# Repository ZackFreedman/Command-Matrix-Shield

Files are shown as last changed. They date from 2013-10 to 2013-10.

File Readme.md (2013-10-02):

The Command Matrix Shield is an expansion board for the ChipKit Uno32 that features an 8x8 LED matrix. The Command Matrix is bidirectional - you can display stuff on it, and sense light hitting it, simultaneously! It's the world's tiniest and most adorable touchscreen!

Important: This shield and the sketches are designed for ChipKIT, specifically the Uno32. THE CODE WILL NOT COMPILE UNDER ARDUINO - JUST MPIDE TARGETING THE UNO32. 

EAGLE files are stored in the folder "Command Matrix Shield PCB".

A straightforward debug program is in the folder "Command Matrix Shield Test". Expected behavior is to send coordinates over hardware serial at 9600 baud when a strong green or blue point light is shone at one of the pixels.

The software and hardware contain a large number of oversights, hacks, cut corners, and plain wrong decisions. Nevertheless, this is known working. Somehow.

Created by Zack Freedman of Voidstar Lab.
@ZackFreedman
yourstruly at zackfreedman com
zackfreedman.com
voidstarlab.com

For more information, visit http://zackfreedman.com/projects/command-matrix-shield/.

The Command Matrix Shield is open hardware licensed under Creative Commons Noncommercial Attribution. More permissive licenses are available on request.

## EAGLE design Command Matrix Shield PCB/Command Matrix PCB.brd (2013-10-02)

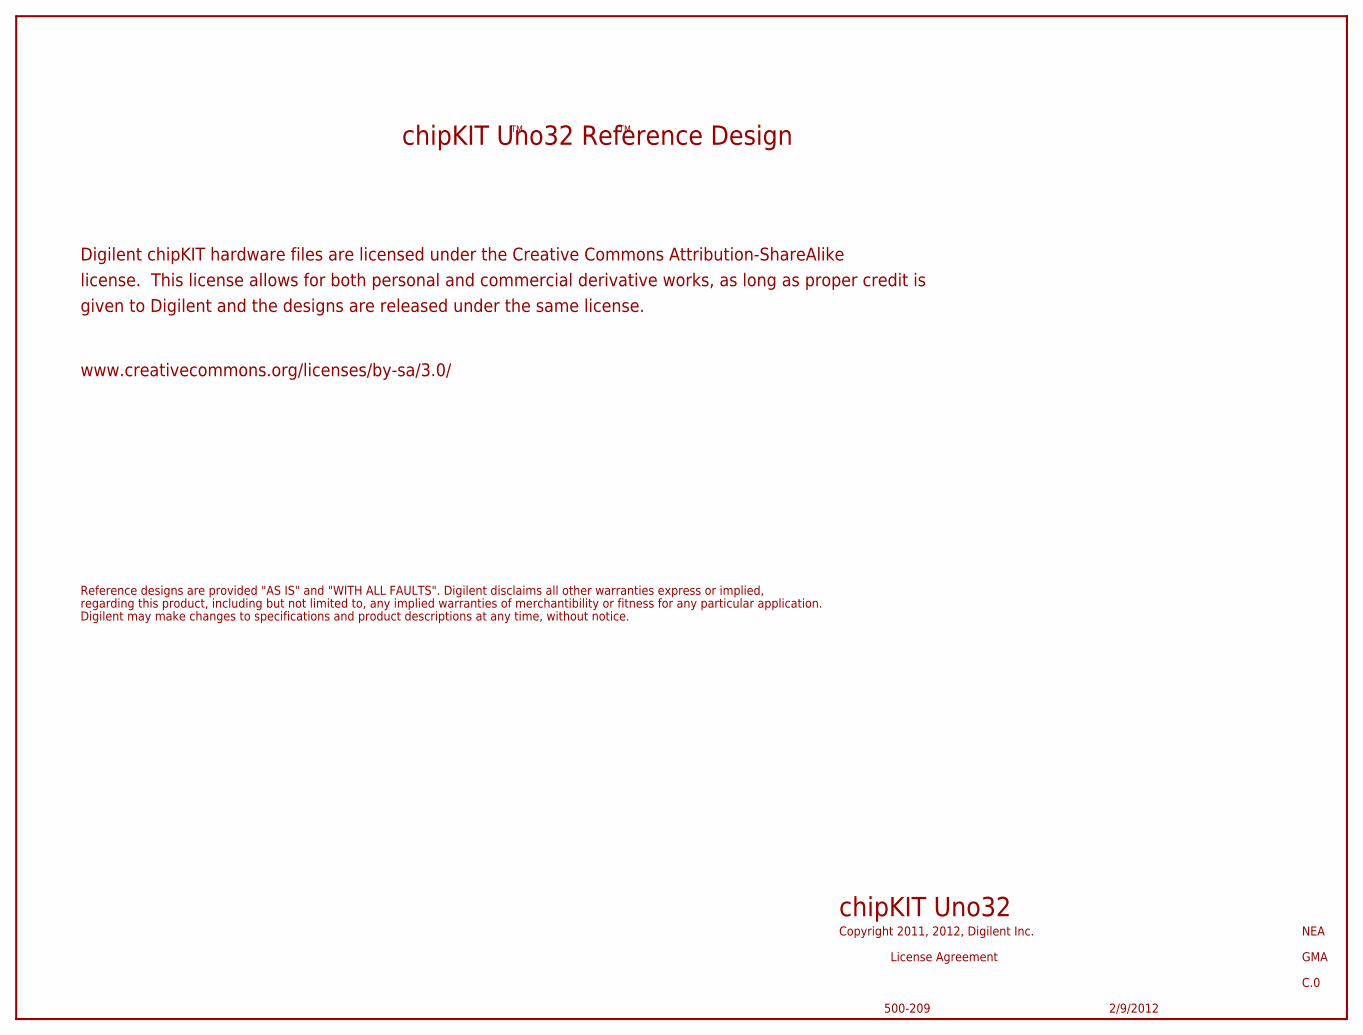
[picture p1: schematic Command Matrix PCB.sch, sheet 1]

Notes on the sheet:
Copyright 2011, 2012, Digilent Inc.
NEA
GMA
License Agreement
500-209
chipKIT Uno32
C.0
2/9/2012
Digilent chipKIT hardware files are licensed under the Creative Commons Attribution-ShareAlike
license. This license allows for both personal and commercial derivative works, as long as proper credit is
given to Digilent and the designs are released under the same license.
chipKIT Uno32 Reference Design
Reference designs are provided "AS IS" and "WITH ALL FAULTS". Digilent disclaims all other warranties express or implied,
regarding this product, including but not limited to, any implied warranties of merchantibility or fitness for any particular application.
Digilent may make changes to specifications and product descriptions at any time, without notice.
www.creativecommons.org/licenses/by-sa/3.0/

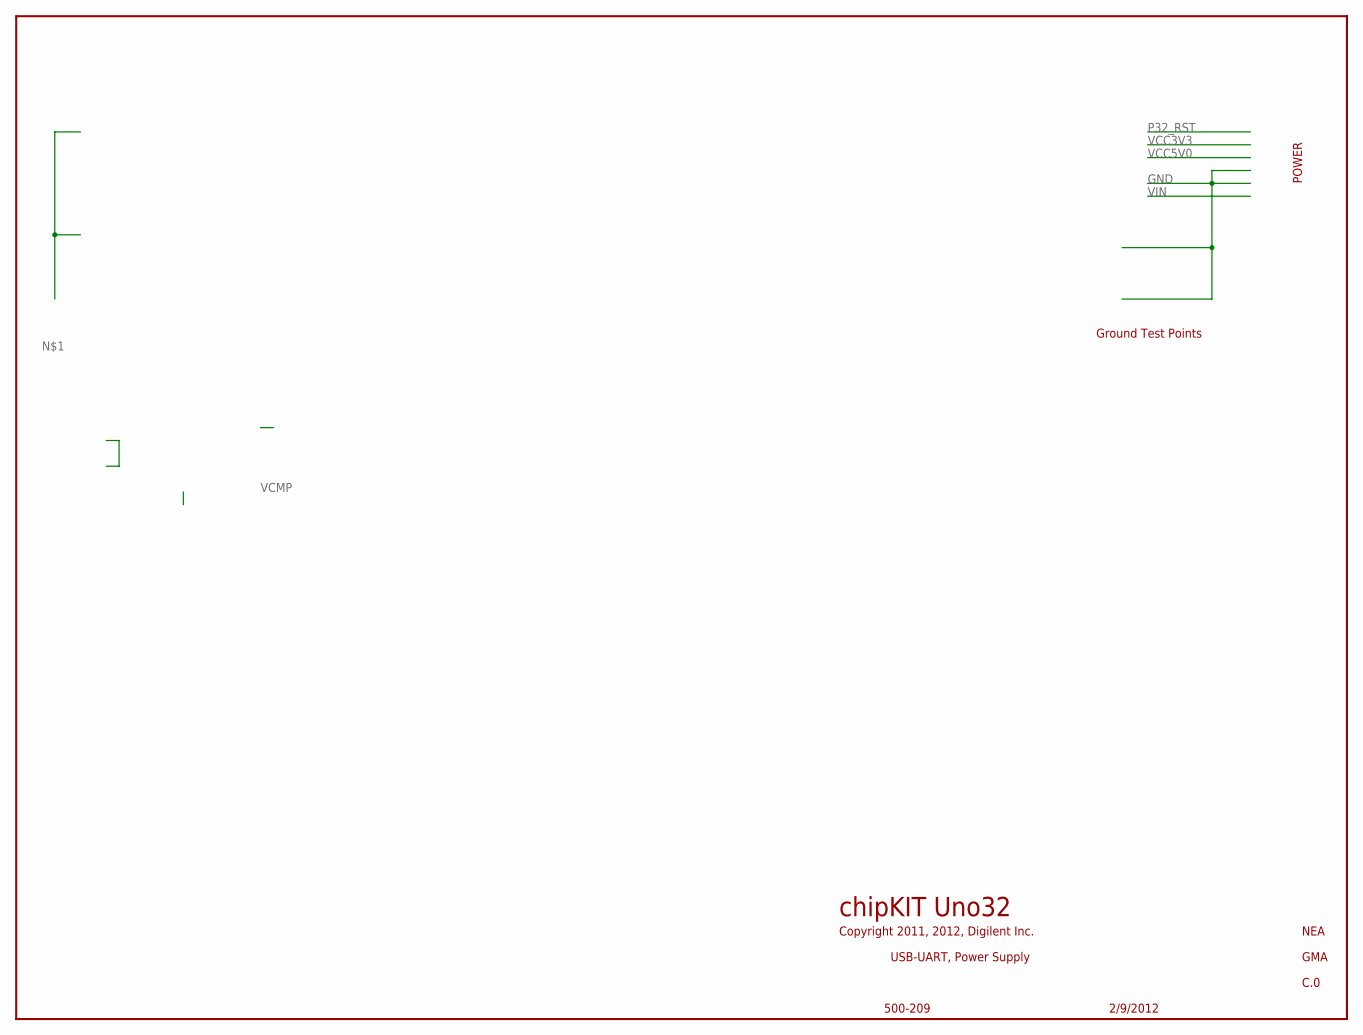
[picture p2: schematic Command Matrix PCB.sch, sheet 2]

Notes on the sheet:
POWER
Copyright 2011, 2012, Digilent Inc.
NEA
GMA
USB-UART, Power Supply
500-209
chipKIT Uno32
C.0
2/9/2012
Ground Test Points

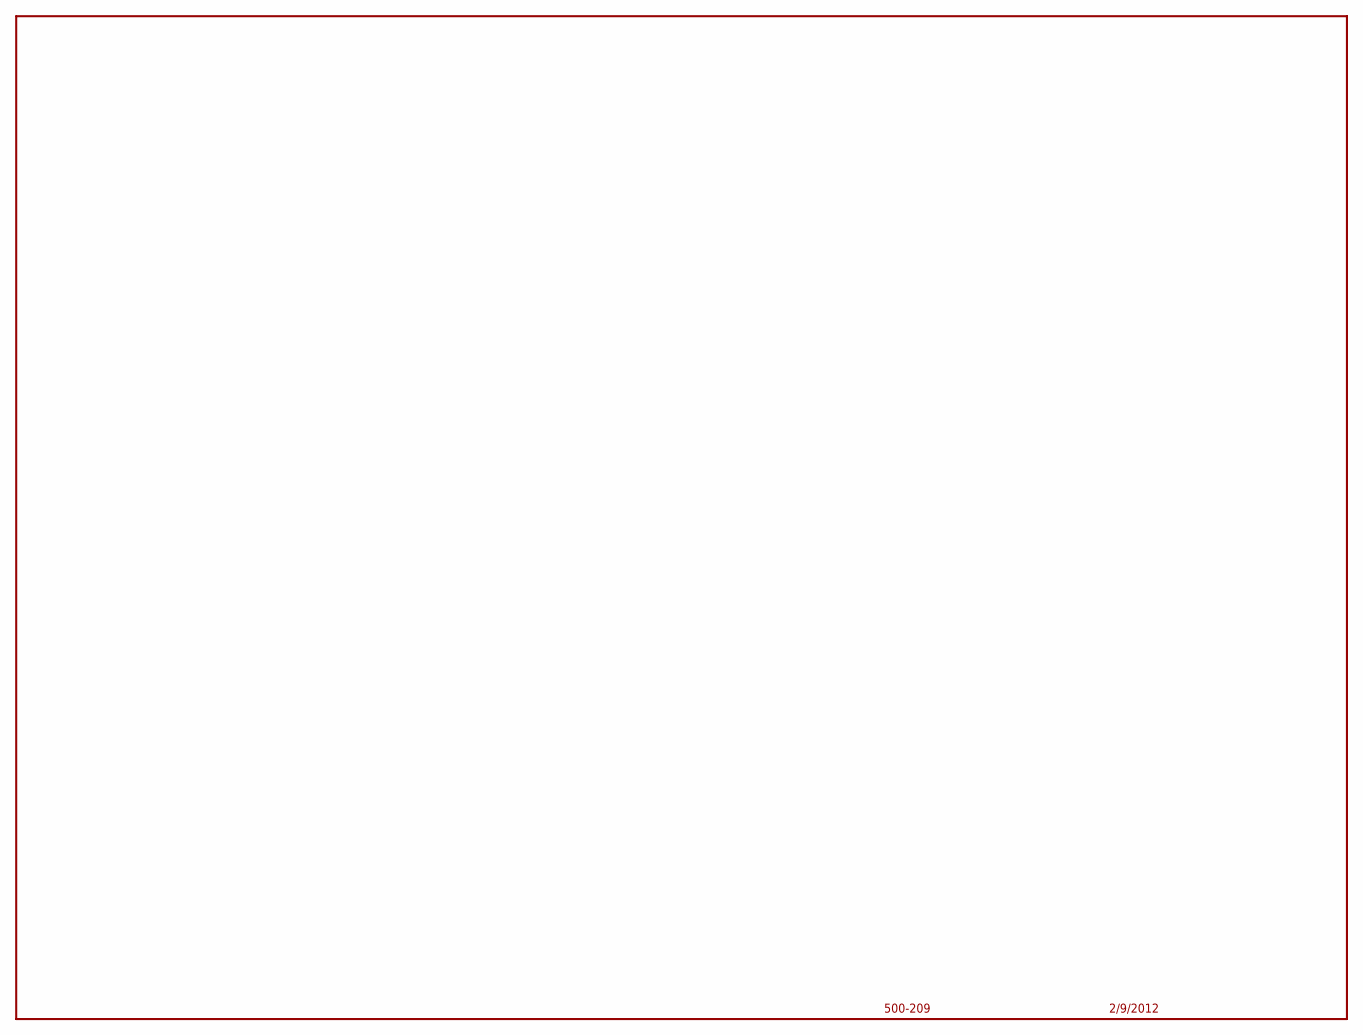
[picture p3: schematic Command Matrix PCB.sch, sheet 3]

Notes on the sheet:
500-209
2/9/2012

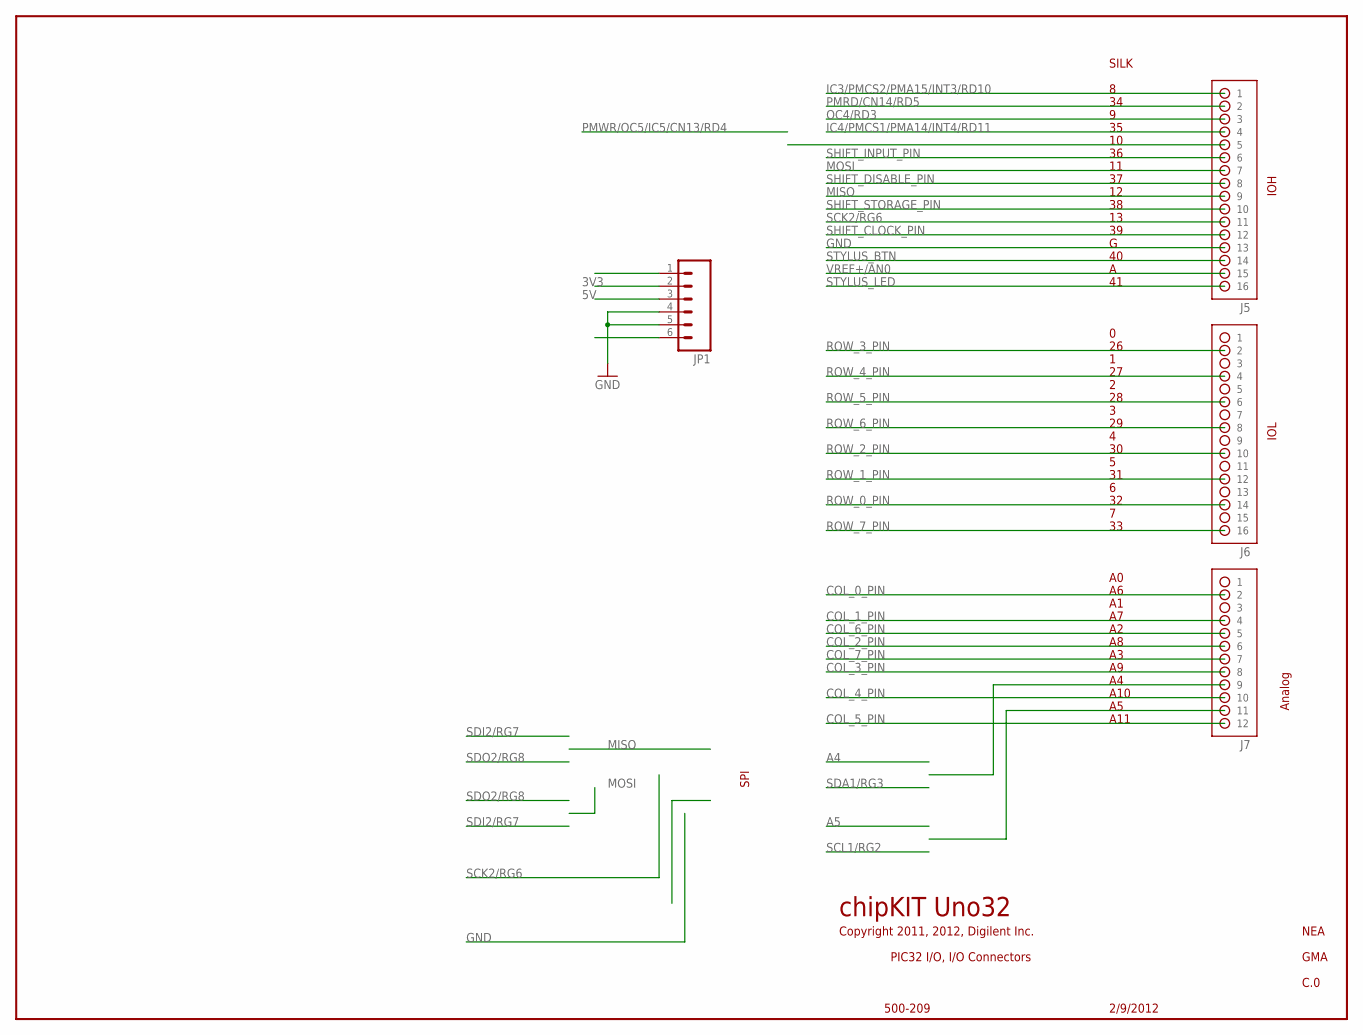
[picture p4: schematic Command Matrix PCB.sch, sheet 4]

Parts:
J5, J6: HDR-2X8
J7: HDR-2X6
JP1: M06SIP; 1X06

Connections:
3V3: JP1.2; also elsewhere on the board
5V: JP1.3; also elsewhere on the board
COL_0_PIN: J7.2; also elsewhere on the board
COL_1_PIN: J7.4; also elsewhere on the board
COL_2_PIN: J7.6; also elsewhere on the board
COL_3_PIN: J7.8; also elsewhere on the board
COL_4_PIN: J7.10; also elsewhere on the board
COL_5_PIN: J7.12; also elsewhere on the board
COL_6_PIN: J7.5; also elsewhere on the board
COL_7_PIN: J7.7; also elsewhere on the board
GND: J5.13, JP1.4, JP1.5; also elsewhere on the board
IC3/PMCS2/PMA15/INT3/RD10: J5.1
IC4/PMCS1/PMA14/INT4/RD11: J5.4
MISO: J5.9
MOSI: J5.7
OC4/RD3: J5.3
PMRD/CN14/RD5: J5.2
RESET: JP1.1
ROW_0_PIN: J6.14; also elsewhere on the board
ROW_1_PIN: J6.12; also elsewhere on the board
ROW_2_PIN: J6.10; also elsewhere on the board
ROW_3_PIN: J6.2; also elsewhere on the board
ROW_4_PIN: J6.4; also elsewhere on the board
ROW_5_PIN: J6.6; also elsewhere on the board
ROW_6_PIN: J6.8; also elsewhere on the board
ROW_7_PIN: J6.16; also elsewhere on the board
SCK2/RG6: J5.11
SHIFT_CLOCK_PIN: J5.12; also elsewhere on the board
SHIFT_DISABLE_PIN: J5.8; also elsewhere on the board
SHIFT_INPUT_PIN: J5.6; also elsewhere on the board
SHIFT_STORAGE_PIN: J5.10; also elsewhere on the board
STYLUS_BTN: J5.14; also elsewhere on the board
STYLUS_LED: J5.16; also elsewhere on the board
VREF+/AN0: J5.15

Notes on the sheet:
IOH
IOL
Analog
SPI
chipKIT Uno32
Copyright 2011, 2012, Digilent Inc.
NEA
PIC32 I/O, I/O Connectors
500-209
GMA
A10
A11
SILK
C.0
2/9/2012

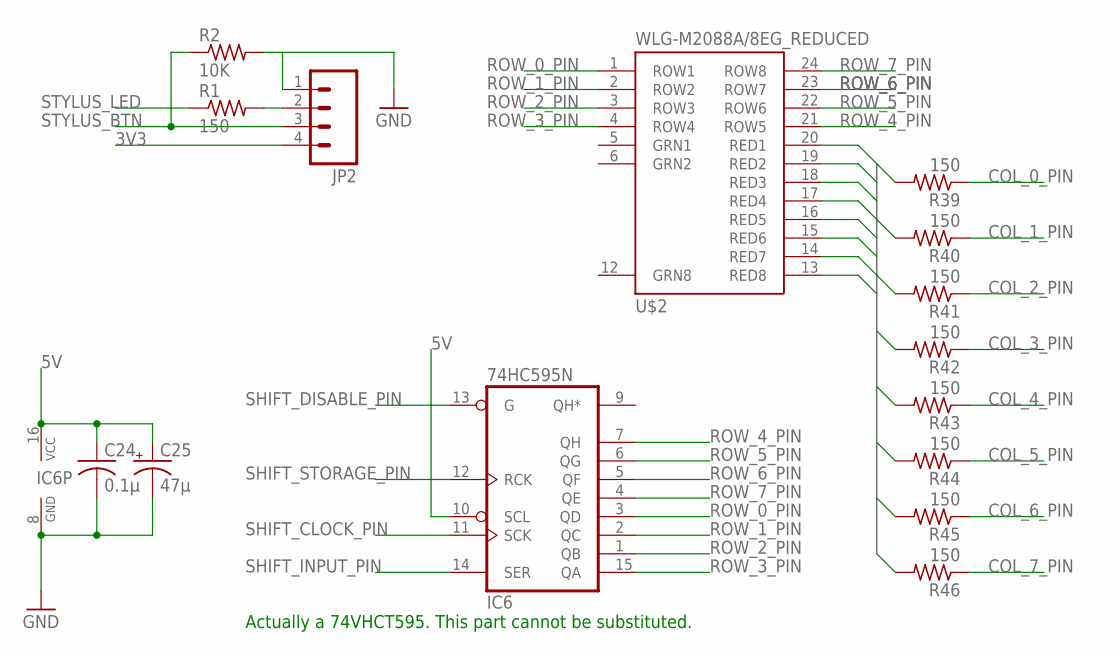
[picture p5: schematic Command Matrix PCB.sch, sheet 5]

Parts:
C24: 0.1µ; C025-025X050
C25: 47µ; E2,5-6E
IC6: 74HC595N; DIL16
JP2: M04PTH; 1X04
R1, R39, R40, R41, R42, R43, R44, R45, R46: 150; 0207/10
R2: 10K; 0207/10
U$2: WLG-M2088A/8EG_REDUCED

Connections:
3V3: JP2.4; also elsewhere on the board
5V: C24.1, C25.+, IC6.10 (SCL), IC6.16 (VCC); also elsewhere on the board
COLUMN_0: R39.2, U$2.20 (RED1)
COLUMN_1: R40.2, U$2.19 (RED2)
COLUMN_2: R41.2, U$2.18 (RED3)
COLUMN_3: R42.2, U$2.17 (RED4)
COLUMN_4: R43.2, U$2.16 (RED5)
COLUMN_5: R44.2, U$2.15 (RED6)
COLUMN_6: R45.2, U$2.14 (RED7)
COLUMN_7: R46.2, U$2.13 (RED8)
COL_0_PIN: R39.1; also elsewhere on the board
COL_1_PIN: R40.1; also elsewhere on the board
COL_2_PIN: R41.1; also elsewhere on the board
COL_3_PIN: R42.1; also elsewhere on the board
COL_4_PIN: R43.1; also elsewhere on the board
COL_5_PIN: R44.1; also elsewhere on the board
COL_6_PIN: R45.1; also elsewhere on the board
COL_7_PIN: R46.1; also elsewhere on the board
GND: C24.2, C25.-, IC6.8 (GND), JP2.1, R2.2; also elsewhere on the board
unnamed: JP2.2, R1.2
ROW_0_PIN: IC6.3 (QD), U$2.1 (ROW1); also elsewhere on the board
ROW_1_PIN: IC6.2 (QC), U$2.2 (ROW2); also elsewhere on the board
ROW_2_PIN: IC6.1 (QB), U$2.3 (ROW3); also elsewhere on the board
ROW_3_PIN: IC6.15 (QA), U$2.4 (ROW4); also elsewhere on the board
ROW_4_PIN: IC6.7 (QH), U$2.21 (ROW5); also elsewhere on the board
ROW_5_PIN: IC6.6 (QG), U$2.22 (ROW6); also elsewhere on the board
ROW_6_PIN: IC6.5 (QF), U$2.23 (ROW7); also elsewhere on the board
ROW_7_PIN: IC6.4 (QE), U$2.24 (ROW8); also elsewhere on the board
SHIFT_CLOCK_PIN: IC6.11 (SCK); also elsewhere on the board
SHIFT_DISABLE_PIN: IC6.13 (G); also elsewhere on the board
SHIFT_INPUT_PIN: IC6.14 (SER); also elsewhere on the board
SHIFT_STORAGE_PIN: IC6.12 (RCK); also elsewhere on the board
STYLUS_BTN: JP2.3, R2.1; also elsewhere on the board
STYLUS_LED: R1.1; also elsewhere on the board

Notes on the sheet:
Actually a 74VHCT595. This part cannot be substituted.

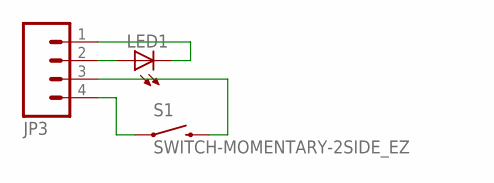
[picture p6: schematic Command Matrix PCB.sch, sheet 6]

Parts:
JP3: M04PTH; 1X04
LED1: LEDSIDEWAYS
S1: SWITCH-MOMENTARY-2SIDE_EZ; TACTILE-PTH-SIDEEZ

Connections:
unnamed: JP3.2, LED1.P$1 (A)
unnamed: JP3.1, LED1.P$2 (C)
unnamed: JP3.3, S1.2
unnamed: JP3.4, S1.1

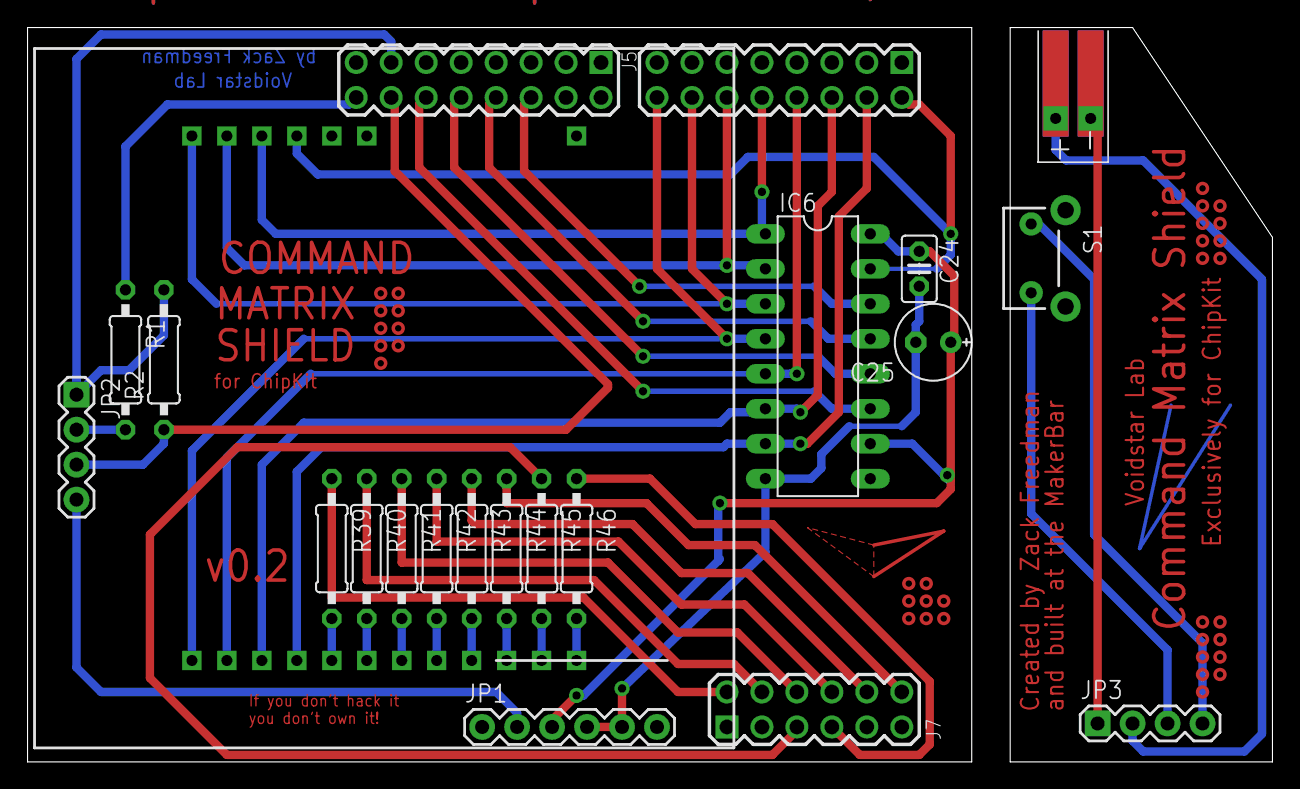
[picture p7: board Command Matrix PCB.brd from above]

Board: 4 copper layers, 90.4 x 53.3 mm, 22 parts (0 on the bottom side), 38 nets.

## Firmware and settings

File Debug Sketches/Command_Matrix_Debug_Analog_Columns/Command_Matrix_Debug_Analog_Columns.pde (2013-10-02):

void setup()
{
  pinMode(2, OUTPUT);
  pinMode(3, OUTPUT);
  digitalWrite(2, LOW);
  digitalWrite(3, LOW);
  
  Serial.begin(9600);
}

void loop()
{
  pinMode(A0, OUTPUT);
  pinMode(A1, OUTPUT);
  digitalWrite(A0, LOW);
  digitalWrite(A1, LOW);
  //delayMicroseconds(1000);
  
  pinMode(A0, INPUT);
  pinMode(A1, INPUT);
  delayMicroseconds(1000);
  
  int analog0 = analogRead(A0);
  int analog1 = analogRead(A1);
  
  if (analog0 < 50 && analog1 < 50) Serial.println("N/A");
  else Serial.println(analog0 > analog1 ? "Col 0" : "Col 1");
  
  delay(10);
}

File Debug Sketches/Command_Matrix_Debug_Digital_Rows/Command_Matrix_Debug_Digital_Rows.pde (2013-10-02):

void setup()
{  
  pinMode(A0, OUTPUT);
  pinMode(A1, OUTPUT);
  digitalWrite(A0, LOW);
  digitalWrite(A1, LOW);
  
  Serial.begin(9600);
}

void loop()
{
  pinMode(2, OUTPUT);
  pinMode(3, OUTPUT);
  digitalWrite(2, HIGH);
  digitalWrite(3, HIGH);
  delayMicroseconds(100);
  
  pinMode(2, INPUT);
  pinMode(3, INPUT);
  digitalWrite(2, LOW);
  digitalWrite(3, LOW);
  delayMicroseconds(100);
  
  int time = 600;
  int value2 = 0;
  int value3 = 0;
  while (time > 0)
  {
    time--;
    
    if (value2 == 0 && digitalRead(2) == LOW) value2 = time;
    if (value3 == 0 && digitalRead(3) == LOW) value3 = time;
    
    if (value2 != 0 && value3 != 0) break;
  }
  
  if (value2 <= 0 && value3 <= 0) Serial.println("N/A");
  else Serial.println(value2 > value3 ? "Row 0" : "Row 1");
  
  /*
  Serial.print(value2);
  Serial.print('\t');
  Serial.println(value3);
  */
  
  delay(10);
}

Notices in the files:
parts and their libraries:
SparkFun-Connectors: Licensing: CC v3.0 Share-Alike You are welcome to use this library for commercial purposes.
